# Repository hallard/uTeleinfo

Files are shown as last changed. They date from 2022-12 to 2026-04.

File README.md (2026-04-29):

# Micro Téléinfo V3

Dongle USB permettant de récupérer les trames téléinformation

Suivez mes nouveautés et autres projets sur mon [blog][4] 

## Historique

**New V3.0**

- Remplacement R3 par un potentiomètre
- Led séparées RX / TX

**Prototype V3.0**

- Réduction taille PCB
- Ajout LED information signal TIC
- Test Led Rouge/Vert pour RX/TX
- Test avec connecteur USB PTH/SMD
- Ajustement résistance TIC 220 Ohm
- Ajustement résistance MOSFET 3.3KOhm
- Changement chip FT230XS par CH9106

**V2.0**

- Version historique

**V3.0 VS V2.0**

V3 vs V2

# Installation et configuration

Les tests suivants sont réalisés depuis un terminal (ou via SSH) sur Rapsberry PI, veillez à bien toujours avoir votre PI à jour avec les commandes suivantes

```shell
sudo apt-get update
sudo apt-get upgrade
```

## Verification du module

Lancer un terminal (ou via SSH), connecter le module puis faites un `dmesg -e`

```shell
[Dec27 11:25] usb 1-1.4: new full-speed USB device number 30 using dwc_otg
[  +0.144735] usb 1-1.4: New USB device found, idVendor=1a86, idProduct=55d4, bcdDevice= 4.43
[  +0.000022] usb 1-1.4: New USB device strings: Mfr=1, Product=2, SerialNumber=3
[  +0.000016] usb 1-1.4: Product: uTinfo-V3.0
[  +0.000015] usb 1-1.4: Manufacturer: CH2i
[  +0.000014] usb 1-1.4: SerialNumber: TINFO-2000
[  +0.001248] cdc_acm 1-1.4:1.0: ttyACM0: USB ACM device
```

On voit bien que le module est bien detecté, dans notre cas le nom de device `/dev/ttyACM0`

## Connecter la téléinfo

Brancher le connecteur vert du module avec un cable (un petit cable fait parfaitement l'affaire comme téléphonique, réseau, alim LED, ...) sur le compteur aux bornes I1 et I2, peut importe le sens ce n'est pas polarisé.

La Led bleu doit clignoter très rapidement (ou être quasi allumée) indiquant que le signal téléinfo est bien présent.

## Test de réception 

### Picocom

Le 1er test est avec un terminal série nommé `picocom` , installation via 

```shell
sudo apt-get install picocom
```

Puis lancer la commande suivante si vous êtes en mode historique
```shell
pi@pi03:~ # picocom -b 1200 -d 7 -p e -f n /dev/ttyACM0 
```

Ou celle ci en mode standard
```shell
pi@pi03:~ # picocom -b 9600 -d 7 -p e -f n /dev/ttyACM0 
```

Vous devriez voir arriver des données sur le termimal 

```shell
picocom v3.1

port is        : /dev/ttyACM0
flowcontrol    : none
baudrate is    : 1200
parity is      : even
databits are   : 7
stopbits are   : 1
escape is      : C-a
local echo is  : no
noinit is      : no
noreset is     : no
hangup is      : no
nolock is      : no
send_cmd is    : sz -vv
receive_cmd is : rz -vv -E
imap is        : 
omap is        : 
emap is        : crcrlf,delbs,
logfile is     : none
initstring     : none
exit_after is  : not set
exit is        : no

Type [C-a] [C-h] to see available commands
Terminal ready
HCHP 002784502 /
PTEC HP..  
IINST 001 X
IMAX 002 A
PAPP 00200 #
HHPHC A ,
MOTDETAT 000000 B
ADCO 021528603314 :
OPTARIF HC.. <
ISOUSC 15 <
HCHC 001096011 X
HCHP 002784502 /
PTEC HP..  
IINST 001 X
IMAX 002 A
PAPP 00180 *
HHPHC A ,
MOTDETAT 000000 B
ADCO 021528603314 :
OPTARIF HC.. <

Terminating...
Skipping tty reset...
Thanks for using picocom
root@pi03:~ # 

```

PS : Pour quitter picocom il faut faire `CTRL-A` puis immédiatement `CRTL-Q`

De plus lorsque picocom est actif et les données reçues par le PI la LED rouge doit aussi se mettre à clignoter 

Schematics

### Test avec Python

Un programme de test basic a aussi été réalisé en python, vous trouverez toute la documentation sur le repo suivant
https://github.com/hallard/teleinfo-test

### Python avancé

Un programme plus avancé été réalisé en python (merci à l'auteur original), vous trouverez toute la documentation sur le repo suivant
https://github.com/hallard/python-teleinfo

### Python publication MQTT

En utilisant le module avancé ci dessous il est extrèmement simple de faire un script python qui publie les données dans MQTT

Installation de la librairie paho-mqtt et des outils MQTT

```shell
pi@pi03:~ # sudo apt-get install mosquitto-clients
pi@pi03:~ # pip install paho-mqtt
```

Créer le script suivant dans le dossier python-teleinfo, par exemple `test.py`

```python
#!/usr/bin/env python
import json
import paho.mqtt.client as mqtt
from teleinfo import Parser
from teleinfo.hw_vendors import UTInfo3
ti = Parser(UTInfo3())
client = mqtt.Client("PI-Demo1")
client.connect("test.mosquitto.org")
while True:
    data = json.dumps(ti.get_frame())
    print(data)
    client.publish("teleinfo/demo", data)
```

Puis le lancer via
```shell
pi@pi03:~/python-teleinfo $ python test.py 
```
Enfin ouvrez un autre shell sue le PI (ou lancer la commande sur votre ordinateur ou utiliser un outil type MQTT Explorer) et vérifier les publication dans MQTT

Et voila le résultat

```shell

pi@pi03:~ # mosquitto_sub -h test.mosquitto.org -t "teleinfo/#"
{"IINST": "001", "MOTDETAT": "000000", "OPTARIF": "HC..", "ADCO": "021528603314", "HCHC": "001096011", "PAPP": "00170", "IMAX": "002", "PTEC": "HP..", "ISOUSC": "15", "HHPHC": "A", "HCHP": "002785290"}
{"IINST": "001", "MOTDETAT": "000000", "OPTARIF": "HC..", "ADCO": "021528603314", "HCHC": "001096011", "PAPP": "00160", "IMAX": "002", "PTEC": "HP..", "ISOUSC": "15", "HHPHC": "A", "HCHP": "002785291"}
{"IINST": "001", "MOTDETAT": "000000", "OPTARIF": "HC..", "ADCO": "021528603314", "HCHC": "001096011", "PAPP": "00180", "IMAX": "002", "PTEC": "HP..", "ISOUSC": "15", "HHPHC": "A", "HCHP": "002785291"}
```

Bien entendu c'est un exemple, il faudrait parser les valeurs, potentiellement les convertir en nombre et faire un peu de gestion d'erreur mais les bases fonctionnelles sont là.

# Conception

**Schémas** 

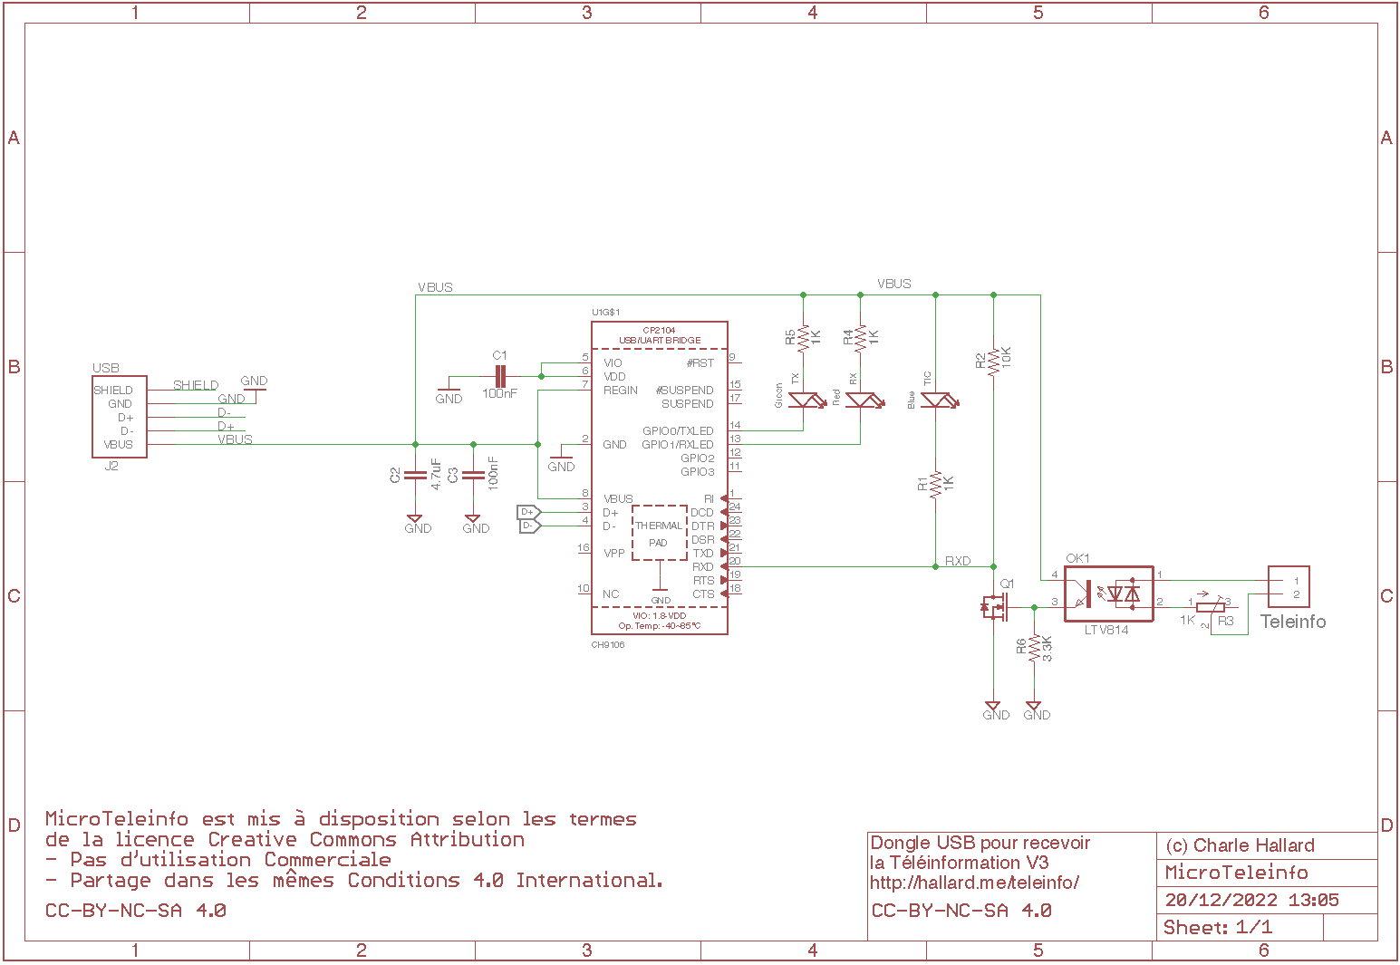
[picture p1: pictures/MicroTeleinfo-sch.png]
Schematics


**Cartes**  

PCB

On PI

# Support et discussions

Si vous rencontrez le moindre soucis ou si vous voulez simplement discuter de votre projet avec ce module n'hésitez pas à utiliser le [forum communautaire](https://community.ch2i.eu/category/9)

# License

   

This work is licensed under a [Creative Commons Attribution-NonCommercial-ShareAlike 4.0 International License](https://creativecommons.org/licenses/by-nc-sa/4.0/)    
If you want to do commercial stuff with this project, please contact [CH2i company](https://ch2i.eu/en#support) so we can organize an simple agreement.

# Trop compliqué de le fabriquer ? 

Vous pouvez commander ce module assemblé et prêt à l'emploi sur [tindie][1] ou sur [Lectronz](https://lectronz.com/products/utinfo).

Les clients européens peuvent préférer commander sur Lectronz, qui propose des moyens de paiement supplémentaires et des prix en euros.





[1]: https://www.tindie.com/products/28873/
[4]: http://hallard.me
[5]: http://hallard.me/teleinfo/
[6]: https://www.tindie.com/products/Hallard/micro-teleinfo/

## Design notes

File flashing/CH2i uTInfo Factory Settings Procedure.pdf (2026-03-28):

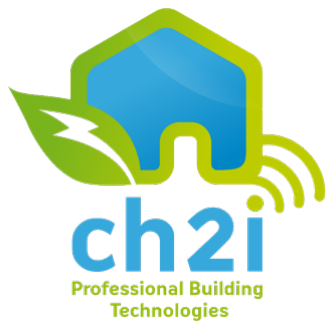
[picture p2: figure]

# Micro Teleinfo

# Factory Settings

# Procedure

Version 1.1
28/03/2026

CH2i MicroTeleinfo factory setting procedure

## WCH USB Flasher tool

To program Micro Teleinfo module you need to install USB CH9102 Flasher tool, this tool can be downloaded here
http://www.wch-ic.com/downloads/CH34xSerCfg_ZIP.html
This procedure has been made with version 1.2 of the tool, latest as today is V1.5 but has not been tested/validated yet, so to be sure, use V1.2 version
Once installed you can launch the Flasher tool, you should get a screen like following:

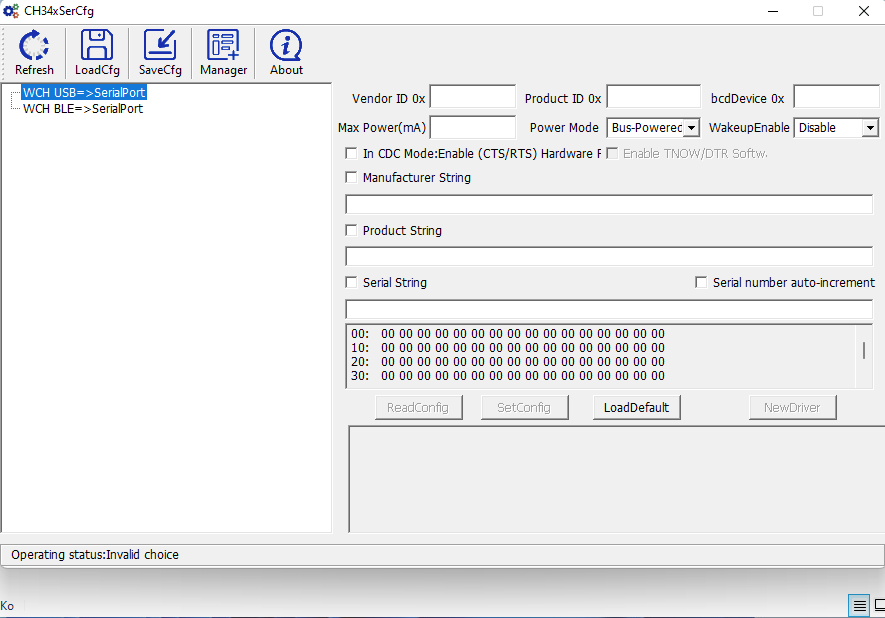
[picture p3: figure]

## USB connection

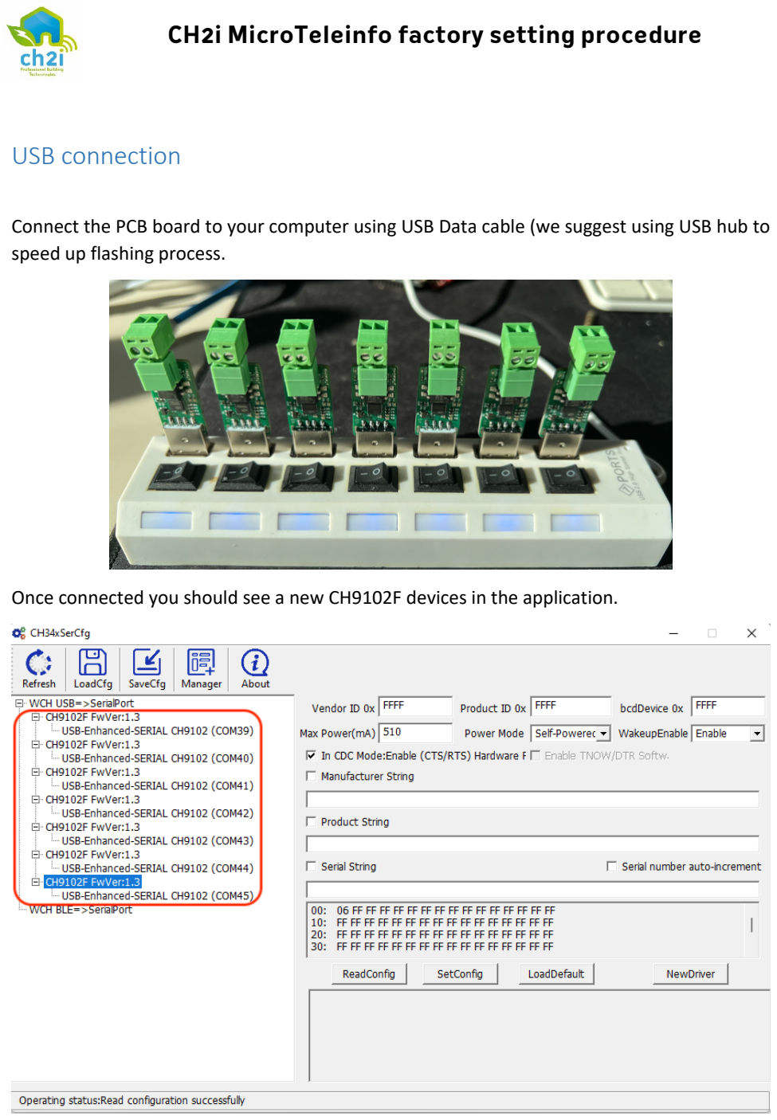
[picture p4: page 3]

Connect the PCB board to your computer using USB Data cable (we suggest using USB hub to speed up flashing process.

Once connected you should see a new CH9102F devices in the application.

Select the 1st one and click on LOADCFG, select config file CH9102F-CH2I.CFG sent by CH2i:
1) Verify that all the parameters are correct as follow
2) Serial String is the only parameter that change for each device

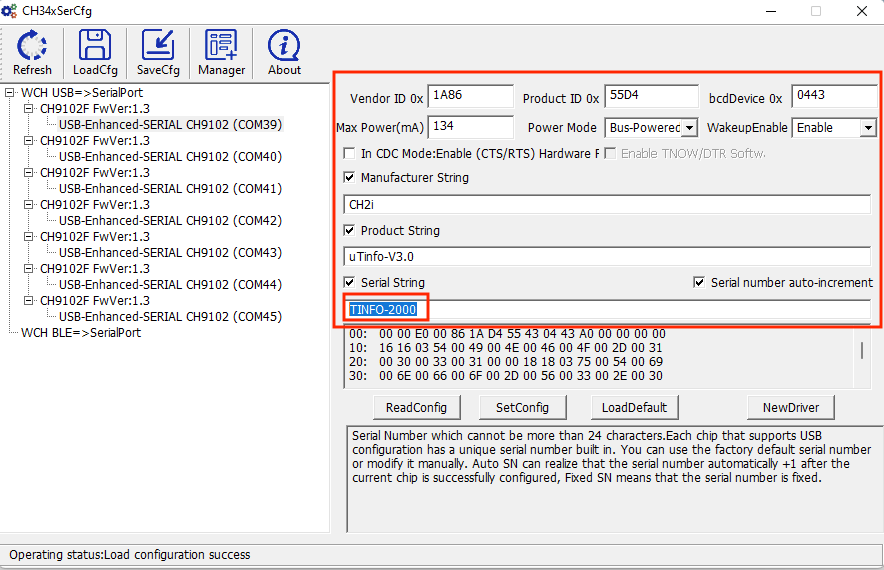
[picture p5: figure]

Each device needs to have it own serial number starting at 2500 with the following names TINFO-2500, TINFO-2501, …, TINFO-2249

Once done click on SETCONFIG and once done you need to select next device, but parameters are removed when changing device so after selecting new device, you need to click on LOADCFG button again and manually change Serial String incrementing to +1

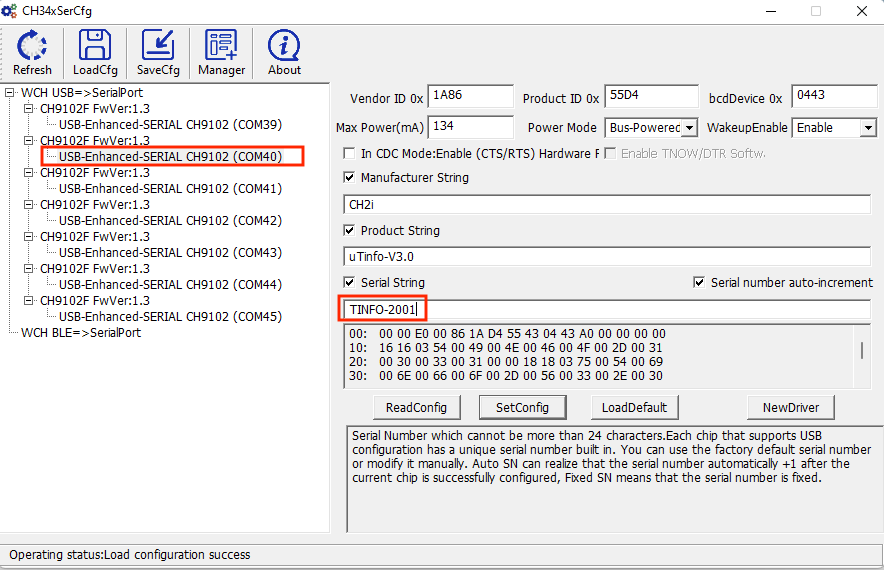
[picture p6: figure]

TIP : when checking Serial Number auto increment, after programming one module Serial number is incremented buy you need to save config (click on SAVECFG) selecting yes when asked to replace old file. Then you can select next module and click on LOADCFG and Serial Number will be the correct one.

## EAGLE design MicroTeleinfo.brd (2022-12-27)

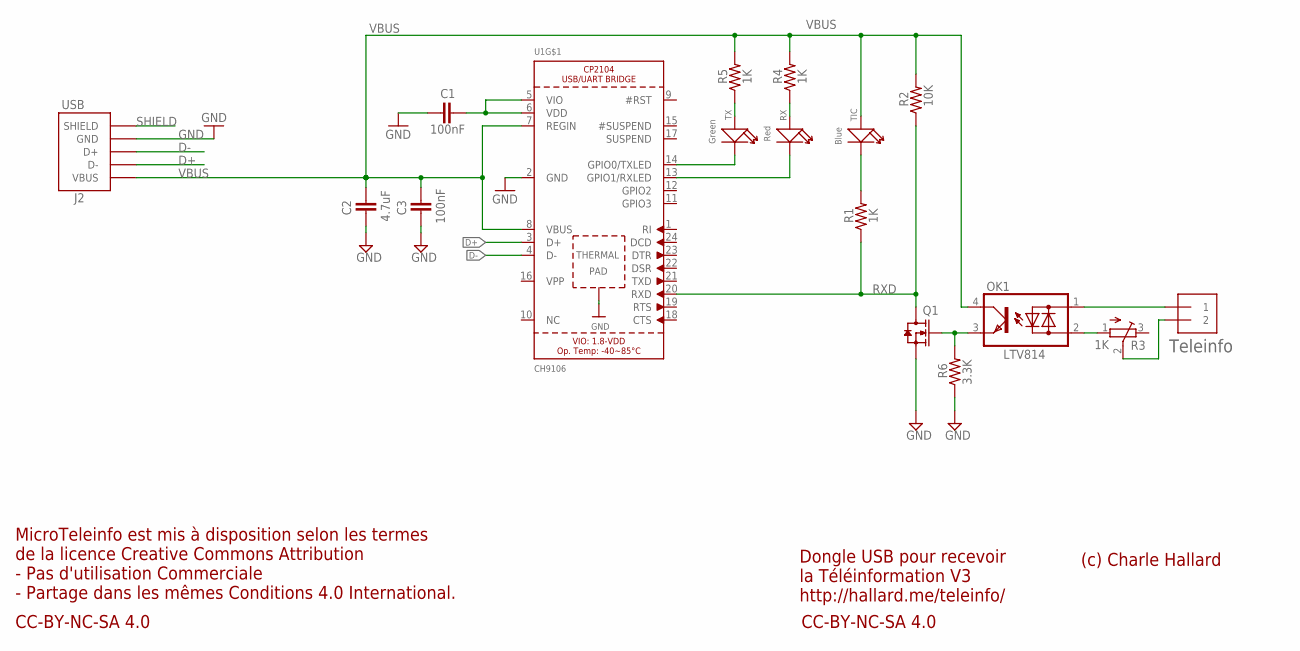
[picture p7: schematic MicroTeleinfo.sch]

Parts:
C1, C3: 100nF; 0402-CAP-OK
C2: 4.7uF; 0402-CAP-OK
J1: 1X2-3.5MM
J2: USB; GCT_USB1061-XX-X-X_REVA
OK1: LTV814; DIL4-SMD
Q1: CJ2302; SOT-323-3
R1, R4, R5: 1K; 0402-RES
R2: 10K; 0402-RES
R3: 1K; TC33X
R6: 3.3K; 0402-RES
RX: Red; LED-0402
TIC: Blue; LED-0402
TX: Green; LED-0402
U1: CH9106; QFN24_4MM_SMSC

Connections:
D+: J2.3 (D+), U1.3 (D+)
D-: J2.2 (D-), U1.4 (D-)
GND: C1.1, C2.2, C3.1, J2.4 (GND), Q1.2 (S), R6.1, U1.2 (GND), U1.THERM (TP)
unnamed: OK1.3 (E), Q1.1 (G), R6.2
unnamed: C1.2, U1.5 (VIO), U1.6 (VDD)
unnamed: OK1.2 (AC2), R3.1 (A)
unnamed: J1.1, OK1.1 (AC1)
unnamed: J1.2, R3.2 (S)
unnamed: R4.1, RX.+
unnamed: R5.1, TX.+
unnamed: R1.2, TIC.-
unnamed: TX.-, U1.14 (GPIO0/TXLED)
unnamed: RX.-, U1.13 (GPIO1/RXLED)
RXD: Q1.3 (D), R1.1, R2.1, U1.20 (RXD)
SHIELD: J2.5 (SHIELD), J2.6 (SHIELD)
VBUS: C2.1, C3.2, J2.1 (VBUS), OK1.4 (C), R2.2, R4.2, R5.2, TIC.+, U1.7 (REGIN), U1.8 (VBUS)

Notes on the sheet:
Dongle USB pour recevoir la Téléinformation V3 http://hallard.me/teleinfo/
Teleinfo
CC-BY-NC-SA 4.0
MicroTeleinfo est mis à disposition selon les termes de la licence Creative Commons Attribution - Pas d'utilisation Commerciale - Partage dans les mêmes Conditions 4.0 International.
(c) Charle Hallard

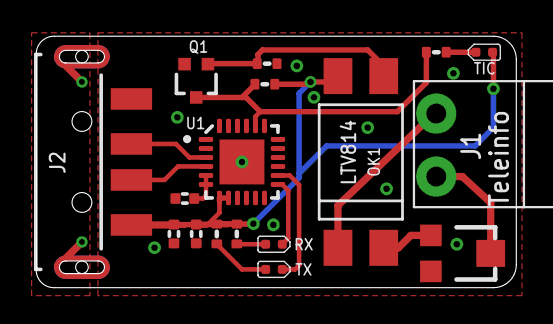
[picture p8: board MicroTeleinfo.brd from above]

Board: 2 copper layers, 26.7 x 14.0 mm, 18 parts (1 on the bottom side), 16 nets.

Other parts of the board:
U$2: LOGO_CH2I_015_COPPER

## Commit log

2026-03-28 FACTORY : Updated procedure for new batch
    - Updated procedure for batch 2500-2749
    - Updated config file to start 2500-2749
    - added V1.2 version of flashing tool for reference
    [CH9102F-CH2i.cfg]
2026-04-29 Switch to CC BY-NC-SA 4.0 license, add LICENSE file

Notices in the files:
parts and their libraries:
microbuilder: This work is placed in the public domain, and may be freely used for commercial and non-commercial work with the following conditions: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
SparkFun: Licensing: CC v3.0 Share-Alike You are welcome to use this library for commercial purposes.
